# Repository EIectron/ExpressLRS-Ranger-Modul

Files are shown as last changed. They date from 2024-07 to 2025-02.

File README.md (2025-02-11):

<div align="center">
  <b>
   <h1>
      ExpressLRS Ranger
   </h1>
   <h6>
     V1
   </h6>
  </b>

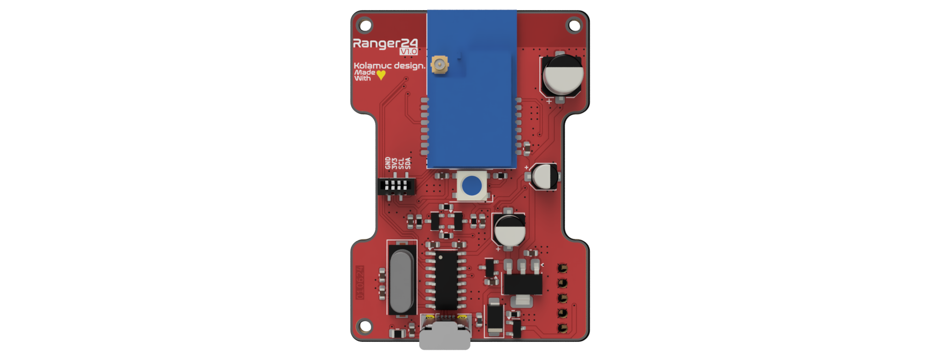
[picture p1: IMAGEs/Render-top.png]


</div>

## Features:
* E28 LoRa Modul
* ESP32 D4 Modul
* W2812B RGB Led
* I2C Screen Support

[Video](https://youtube.com/shorts/PznK_D05IgE)

### Build
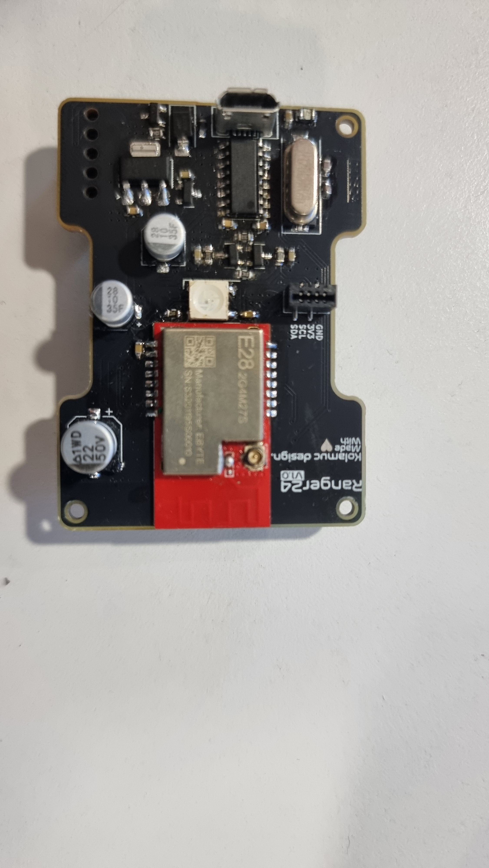
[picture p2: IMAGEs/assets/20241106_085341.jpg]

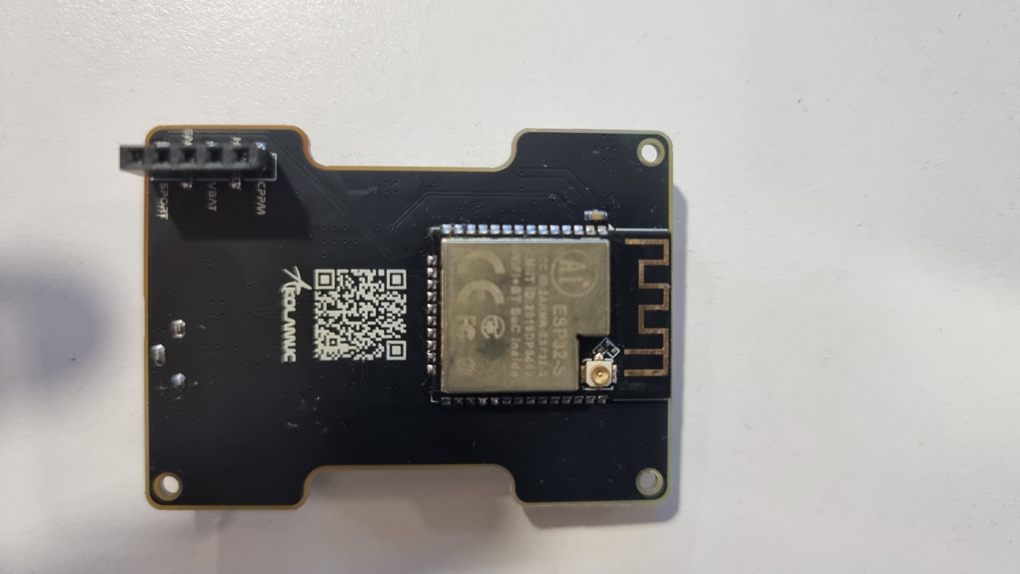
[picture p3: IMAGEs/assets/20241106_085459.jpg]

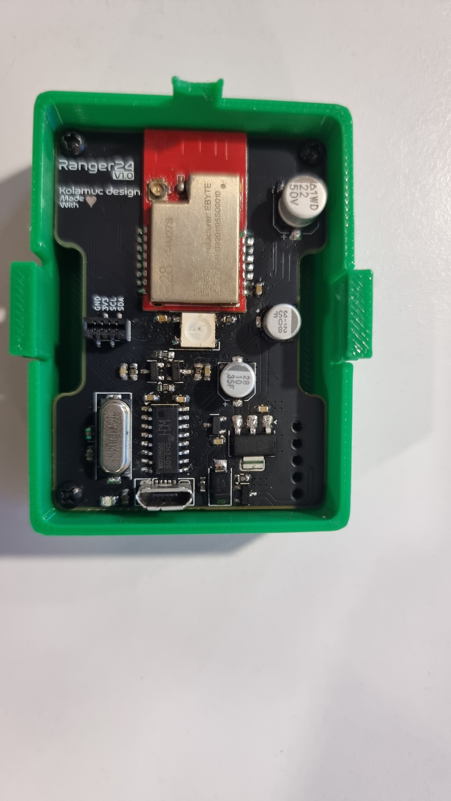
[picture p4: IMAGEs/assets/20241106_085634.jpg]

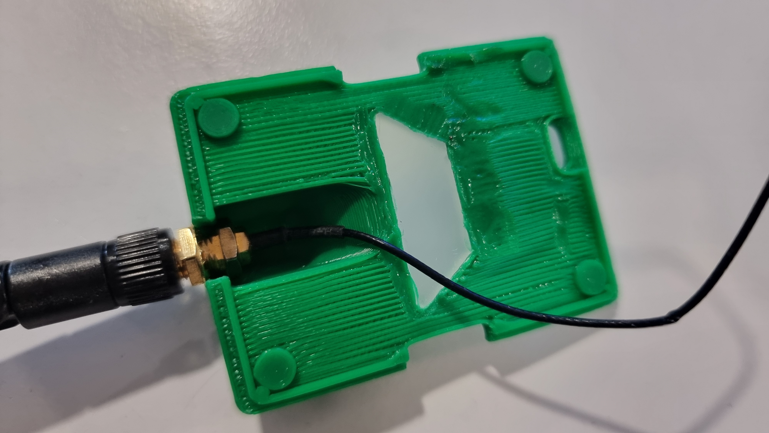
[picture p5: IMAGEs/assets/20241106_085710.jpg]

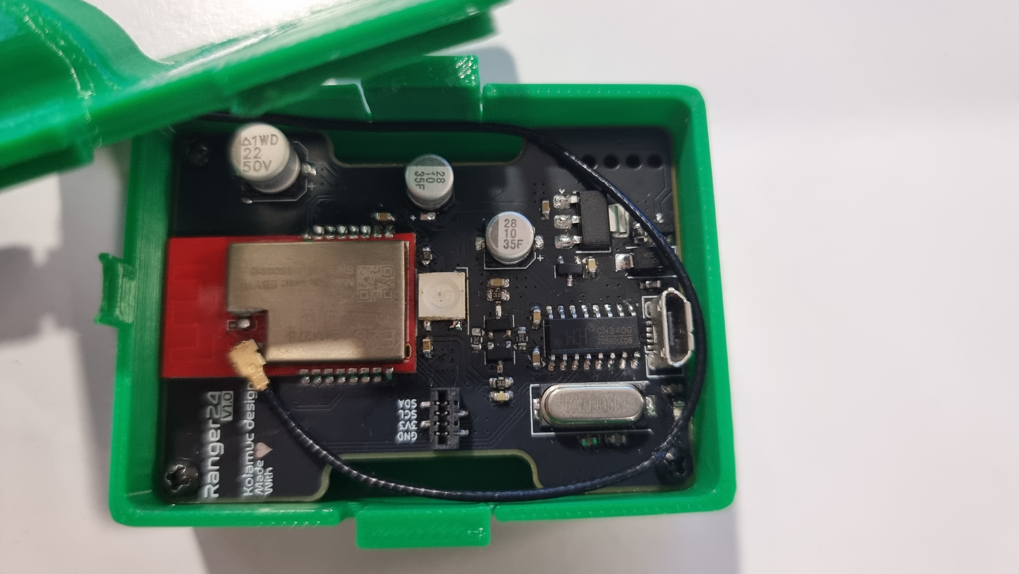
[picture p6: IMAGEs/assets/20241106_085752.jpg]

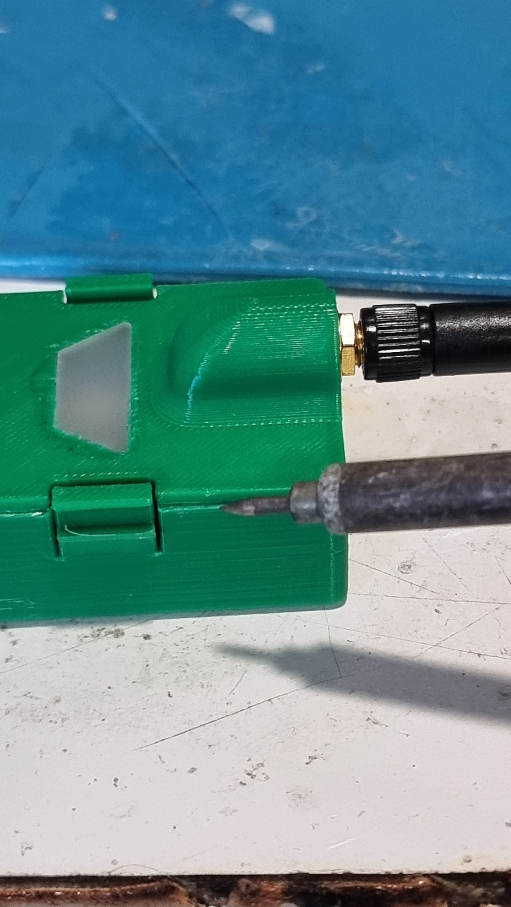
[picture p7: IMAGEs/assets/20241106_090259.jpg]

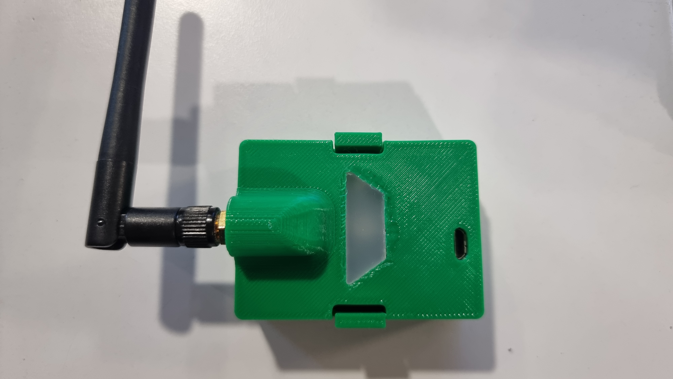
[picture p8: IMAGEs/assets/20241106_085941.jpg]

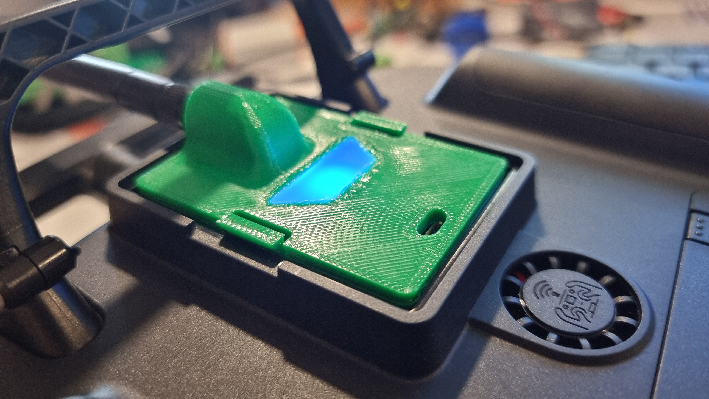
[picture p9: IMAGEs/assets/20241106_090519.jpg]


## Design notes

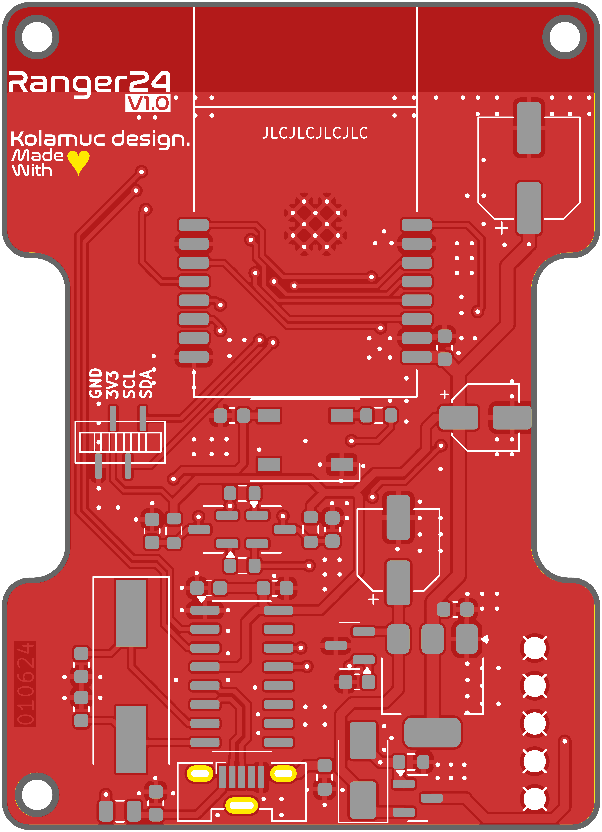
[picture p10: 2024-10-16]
IMAGEs/Ranger24-/top.png

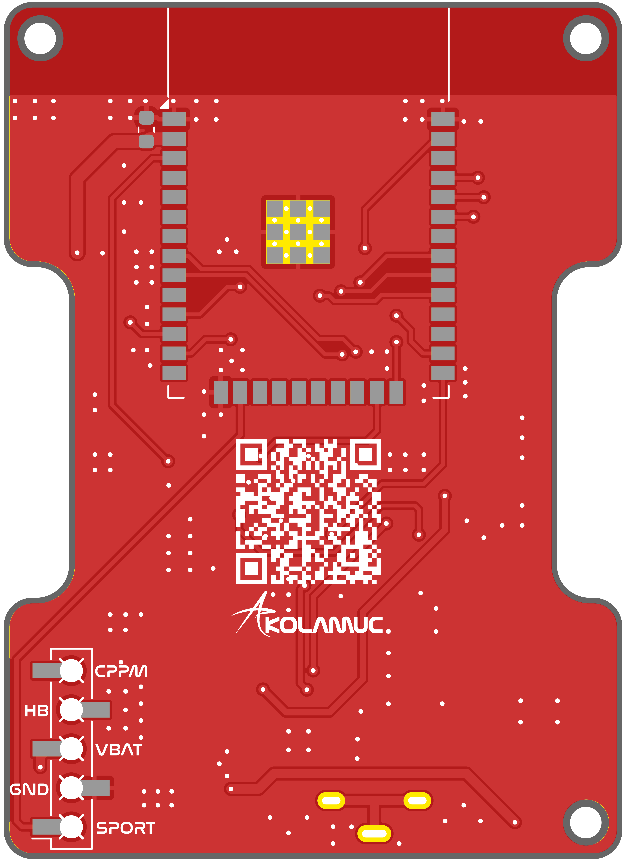
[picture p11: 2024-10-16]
IMAGEs/Ranger24-/bottom.png

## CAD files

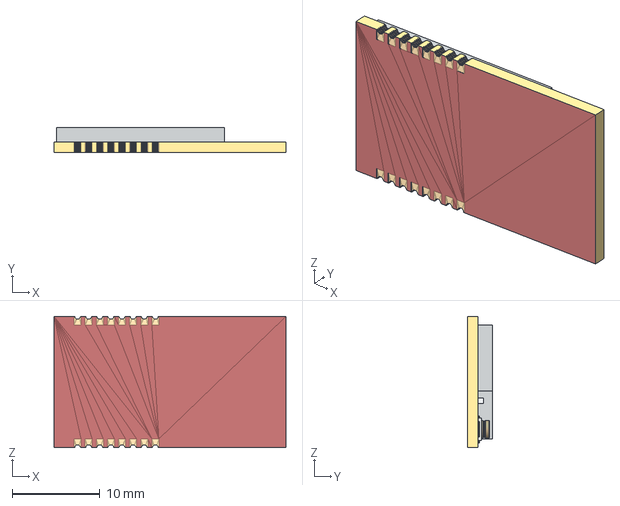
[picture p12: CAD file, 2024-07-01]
3D/E28-2G4M27S.step
26.5 x 2.80 x 15.0 mm
E28-1

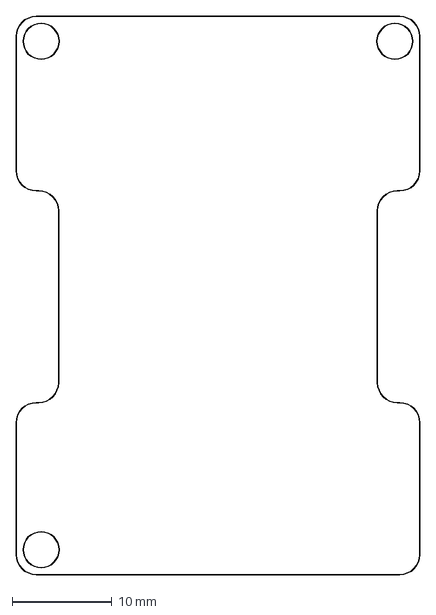
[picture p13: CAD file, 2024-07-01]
PCB-Dimension.dxf
40.5 x 56.0 mm

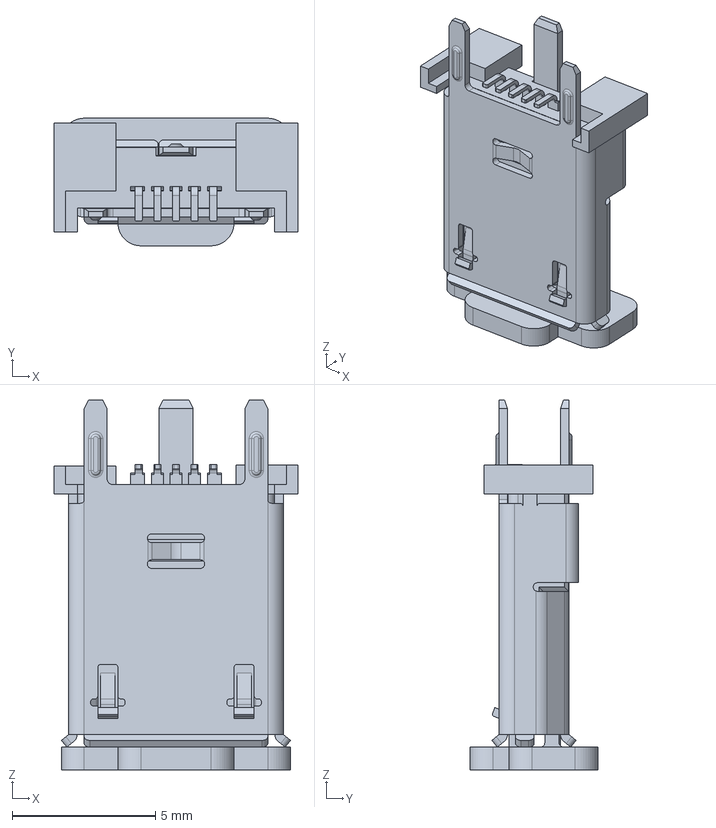
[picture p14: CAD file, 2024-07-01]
3D/Molex-105133-0031.stp
8.50 x 4.45 x 12.9 mm

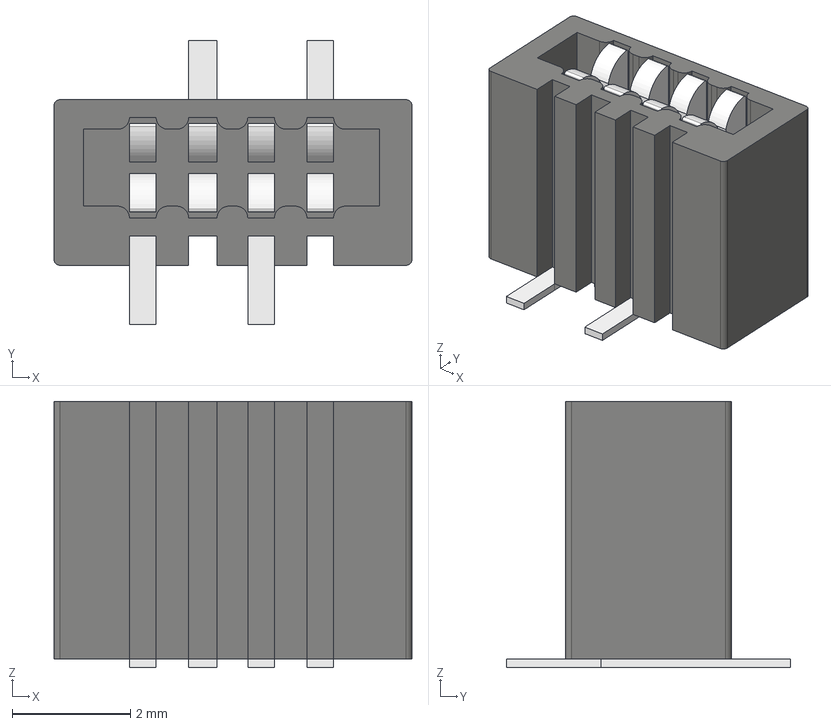
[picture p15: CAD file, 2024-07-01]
3D/DS1020-05-04BT1.step
6.05 x 4.80 x 4.50 mm

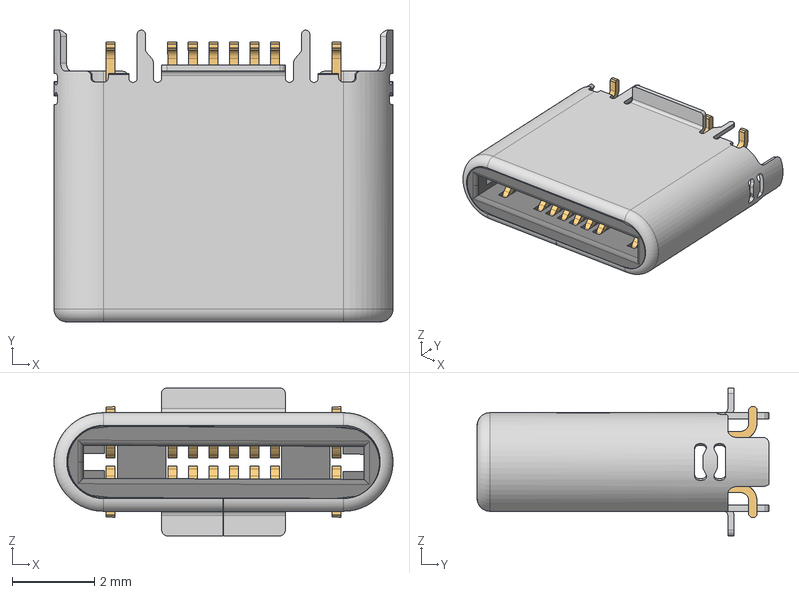
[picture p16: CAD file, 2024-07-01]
3D/629712010214.step
8.25 x 7.10 x 3.60 mm
629712010214_Peg x 2
629712010214_Ground spring
629712010214_Shielding
629712010214_Housing
629712010214_Pin x 16

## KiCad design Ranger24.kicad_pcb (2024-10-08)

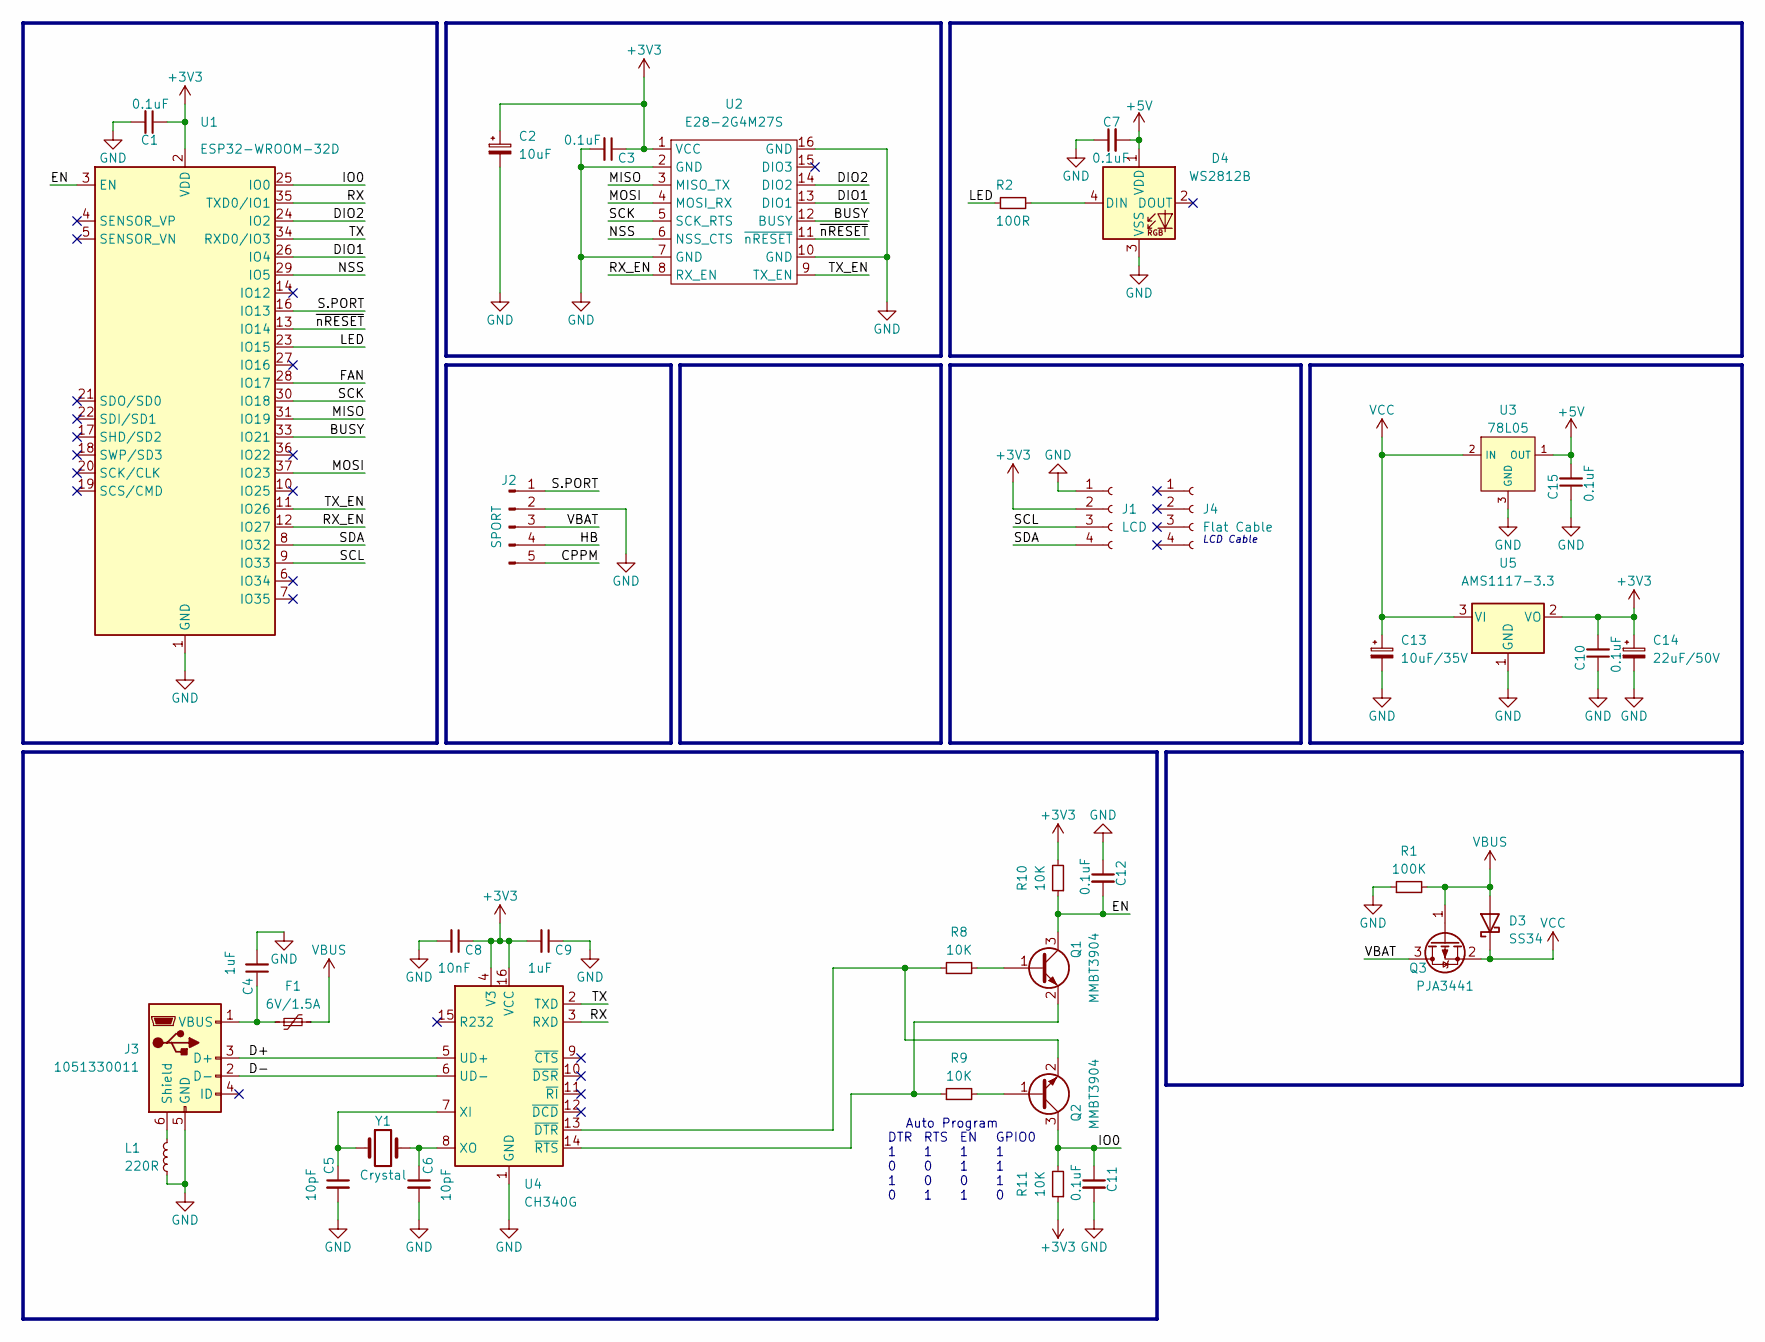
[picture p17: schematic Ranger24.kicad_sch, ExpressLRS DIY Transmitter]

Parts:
C1, C3, C7, C10, C11, C12, C15: 0.1uF; C_0603_1608Metric
C2: 10uF; CP_Elec_4x5.4
C4, C9: 1uF; C_0603_1608Metric
C5, C6: 10pF; C_0603_1608Metric
C8: 10nF; C_0603_1608Metric
C13: 10uF/35V; CP_Elec_5x5.3
C14: 22uF/50V; CP_Elec_6.3x5.7
D3: SS34; D_SMA
D4: WS2812B; LED_WS2812B_PLCC4_5.0x5.0mm_P3.2mm
F1: 6V/1.5A; Fuse_0805_2012Metric
J1: LCD; DS1020-05-04BT1
J2: SPORT; DS1023-10-1X5B81XTX
J3: 1051330011; USB_Micro-B_Molex-105133-0031
J4: Flat Cable
L1: 220R; L_0603_1608Metric
Q1, Q2: MMBT3904; SOT-23
Q3: PJA3441; SOT-23
R1: 100K; R_0603_1608Metric
R2: 100R; R_0603_1608Metric
R8, R9, R10, R11: 10K; R_0603_1608Metric
U1: ESP32-WROOM-32D; ESP32-WROOM-32
U2: E28-2G4M27S
U3: 78L05; SOT-23
U4: CH340G; SOIC-16_3.9x9.9mm_P1.27mm
U5: AMS1117-3.3; SOT-223-3_TabPin2
Y1: Crystal; Crystal_SMD_HC49-SD

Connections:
+3V3: C1.1, C2.1, C3.1, C8.1, C9.2, C10.2, C14.1, J1.2, R10.2, R11.1, U1.2 (VDD), U2.1 (VCC), U4.4 (V3), U4.16 (VCC), U5.2 (VO)
+5V: C7.2, C15.2, D4.1 (VDD), U3.1 (OUT)
/BUSY: U1.33 (IO21), U2.12 (BUSY)
/CPPM: J2.5
/D+: J3.3 (D+), U4.5 (UD+)
/D-: J3.2 (D-), U4.6 (UD-)
/DIO1: U1.26 (IO4), U2.13 (DIO1)
/DIO2: U1.24 (IO2), U2.14 (DIO2)
/EN: C12.2, Q1.3 (C), R10.1, U1.3 (EN)
/FAN: U1.28 (IO17)
/HB: J2.4
/IO0: C11.1, Q2.3 (C), R11.2, U1.25 (IO0)
/LED: R2.1, U1.23 (IO15)
/MISO: U1.31 (IO19), U2.3 (MISO_TX)
/MOSI: U1.37 (IO23), U2.4 (MOSI_RX)
/NSS: U1.29 (IO5), U2.6 (NSS_CTS)
/RX: U1.35 (TXD0/IO1), U4.3 (RXD)
/RX_EN: U1.12 (IO27), U2.8 (RX_EN)
/S.PORT: J2.1, U1.16 (IO13)
/SCK: U1.30 (IO18), U2.5 (SCK_RTS)
/SCL: J1.3, U1.9 (IO33)
/SDA: J1.4, U1.8 (IO32)
/TX: U1.34 (RXD0/IO3), U4.2 (TXD)
/TX_EN: U1.11 (IO26), U2.9 (TX_EN)
/VBAT: J2.3, Q3.3 (D)
/~nRESET: U1.13 (IO14), U2.11 (~nRESET)
GND: C1.2, C2.2, C3.2, C4.2, C5.2, C6.2, C7.1, C8.2, C9.1, C10.1, C11.2, C12.1, C13.2, C14.2, C15.1, D4.3 (VSS), J1.1, J2.2, J3.5 (GND), L1.1, R1.1, U1.1 (GND), U1.15 (GND), U1.38 (GND), U1.39 (GND), U2.2 (GND), U2.7 (GND), U2.10 (GND), U2.16 (GND), U3.3 (GND), U4.1 (GND), U5.1 (GND)
unnamed: D4.4 (DIN), R2.2
unnamed: J3.6 (Shield), L1.2
unnamed: C4.1, F1.1, J3.1 (VBUS)
unnamed: Q1.1 (B), R8.2
unnamed: Q1.2 (E), R9.1, U4.14 (~RTS)
unnamed: Q2.1 (B), R9.2
unnamed: Q2.2 (E), R8.1, U4.13 (~DTR)
unnamed: C5.1, U4.7 (XI), Y1.1
unnamed: C6.1, U4.8 (XO), Y1.2
VBUS: D3.2 (A), F1.2, Q3.1 (G), R1.2
VCC: C13.1, D3.1 (K), Q3.2 (S), U3.2 (IN), U5.3 (VI)

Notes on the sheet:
EN 1 1 0 1
DTR 1 0 1 0
Auto Program
GPIO0 1 1 1 0
RTS 1 0 0 1
LCD Cable

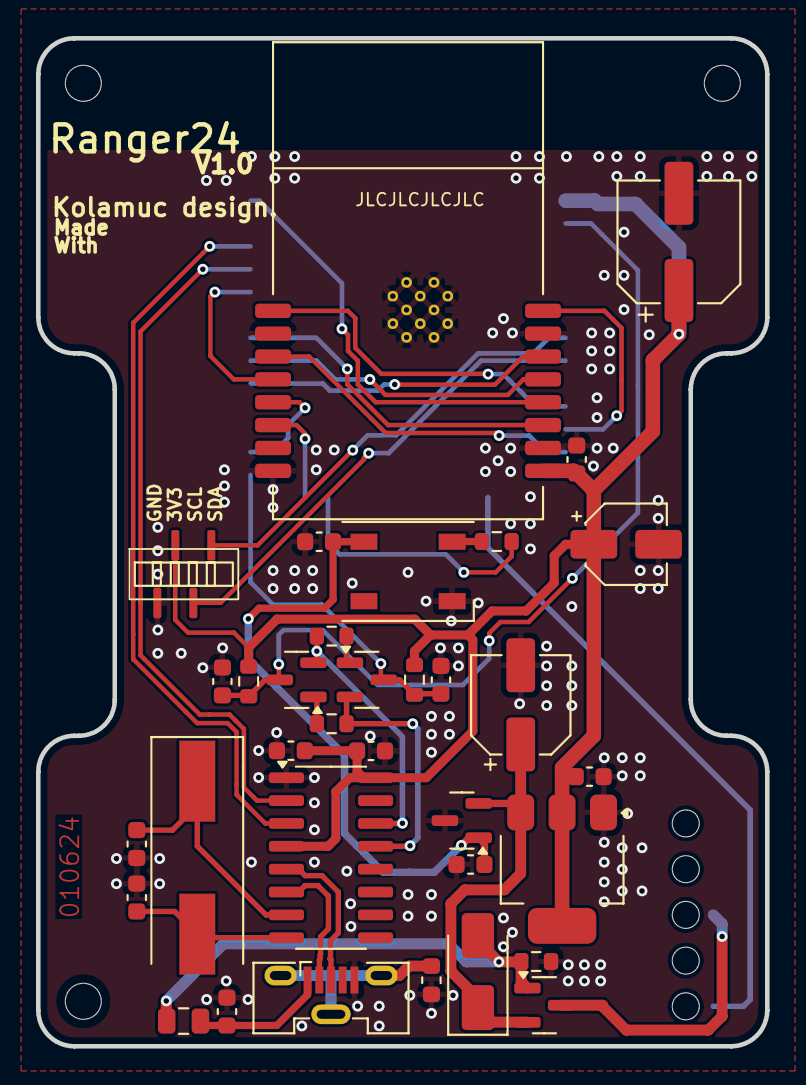
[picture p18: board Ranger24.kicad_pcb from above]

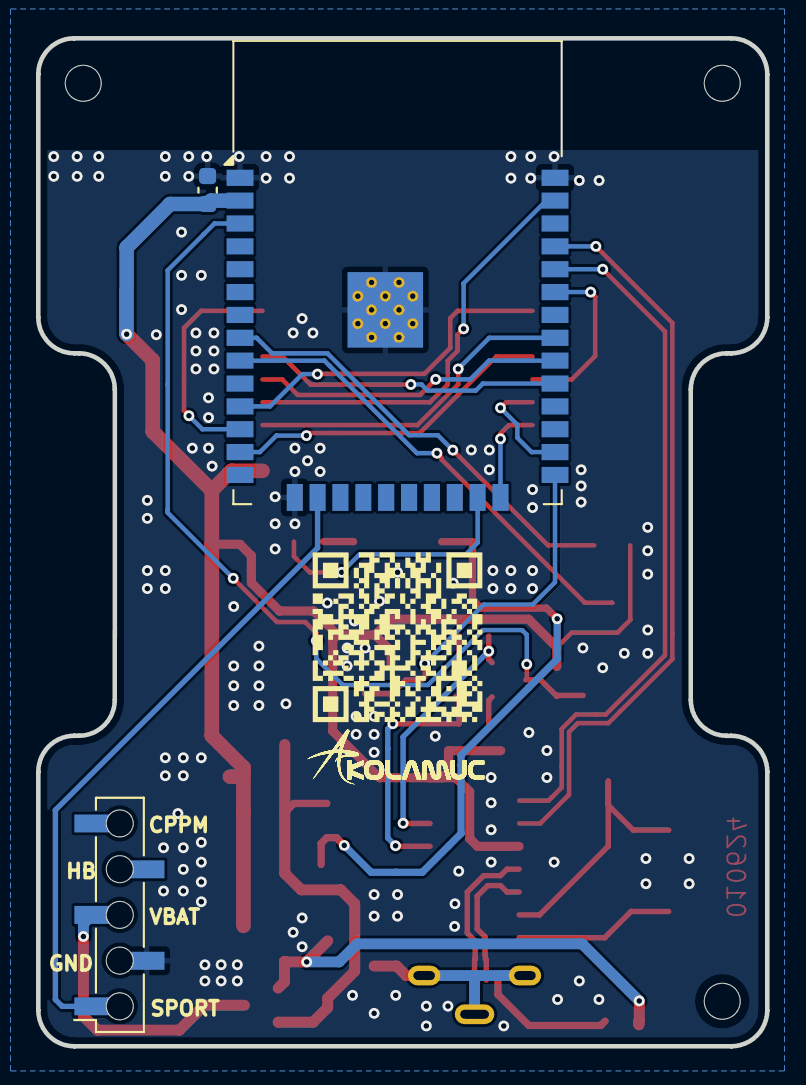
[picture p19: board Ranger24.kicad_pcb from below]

Board: 2 copper layers, 40.5 x 56.0 mm, 37 parts (3 on the bottom side), 35 nets.

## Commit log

2024-07-01 hw design done
    [629712010214.step, DS1020-05-04BT1.step, E28-2G4M27S.step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]
2024-10-08 update
    edit screw holes
    [Ranger24.kicad_pcb]
2024-10-16 update
    image and readme
    [629712010214.step, DS1020-05-04BT1.step, E28-2G4M27S.step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]

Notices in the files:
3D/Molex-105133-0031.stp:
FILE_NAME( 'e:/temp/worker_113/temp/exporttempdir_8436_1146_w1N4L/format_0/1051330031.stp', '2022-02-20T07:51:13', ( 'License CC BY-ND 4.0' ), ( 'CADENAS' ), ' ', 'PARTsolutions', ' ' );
